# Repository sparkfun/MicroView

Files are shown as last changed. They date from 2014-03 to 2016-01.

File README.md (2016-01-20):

MicroView
=============

MicroView

[*SparkFun Microview (DEV-12923)*](https://www.sparkfun.com/products/12923)

The MicroView is a chip-sized Arduino with a built-in OLED. Compatible with the MicroView USB Programmer linked below. 

Repository Contents
-------------------
* **/Datasheets** - Datasheets for the OLED module
* **/Enclosure** - 3D model of the standard Microview Enclosure
* **/Hardware** - All Eagle design files (.brd, .sch)
* **/Libraries** - All Arduino libraries and board examples
* **/Production** - Test bed files and production panel files

Product Versions
----------------
* [DEV-12923](https://www.sparkfun.com/products/12923)- Version 1.0
* [DEV-12924](https://www.sparkfun.com/products/12924)- MicroView USB Programmer version 0.2

License Information
-------------------
The hardware is released under [Creative Commons ShareAlike 4.0 International](https://creativecommons.org/licenses/by-sa/4.0/).
The code is beerware; if you see me (or any other SparkFun employee) at the local, and you've found our code helpful, please buy us a round!

Distributed as-is; no warranty is given.

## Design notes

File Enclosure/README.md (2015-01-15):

MicroView-Enclosure
===================

MicroView Enclosure as 3D printable STL Files

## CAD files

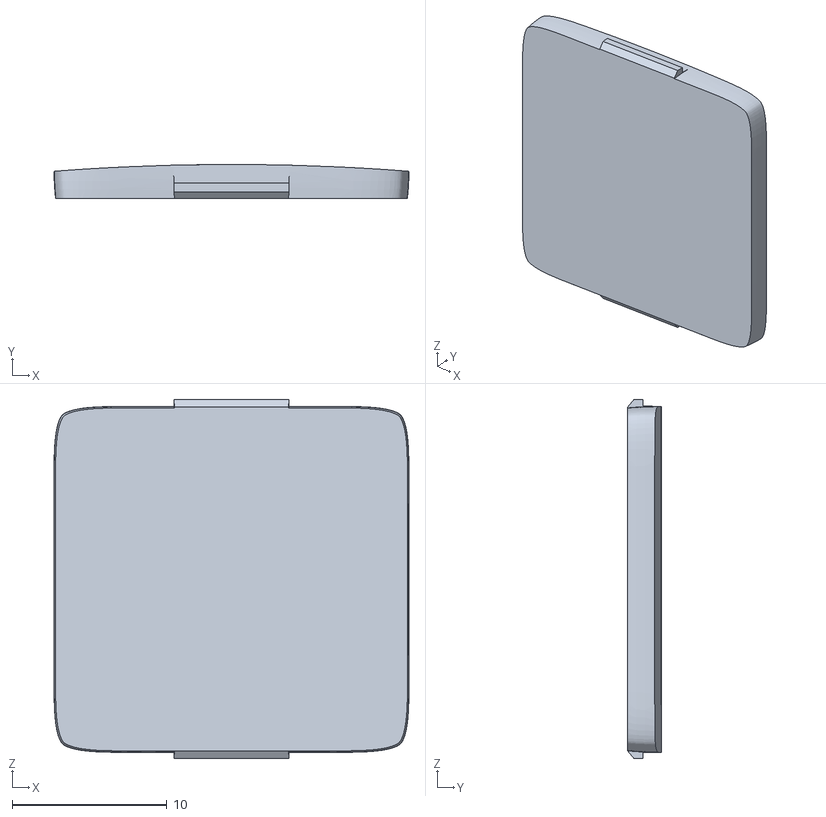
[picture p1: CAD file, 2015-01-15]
Enclosure/GKM-001_R05_ASSY_CHIP - GKM-002_R05_CHIP_UPPER_HOUSING-1.STL
22.9 x 2.20 x 23.2

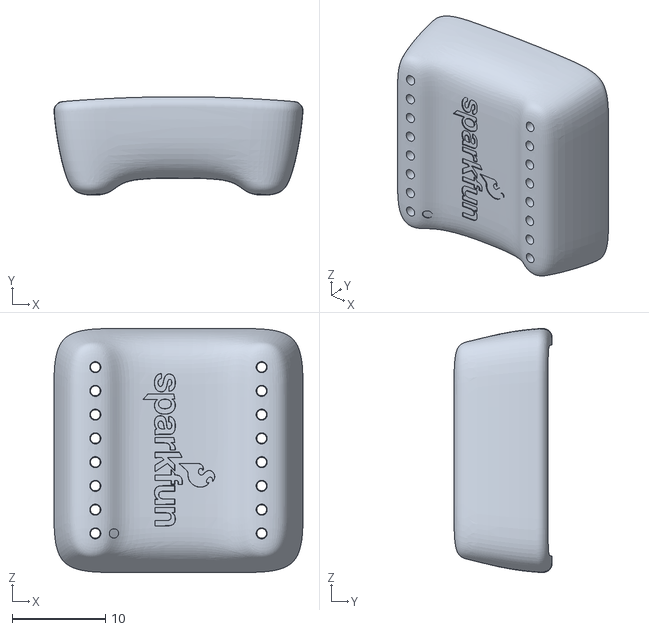
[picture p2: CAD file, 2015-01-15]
Enclosure/GKM-001_R05_ASSY_CHIP - GKM-003_R05_CHIP_LOWER_HOUSING-1.STL
26.7 x 10.5 x 26.1

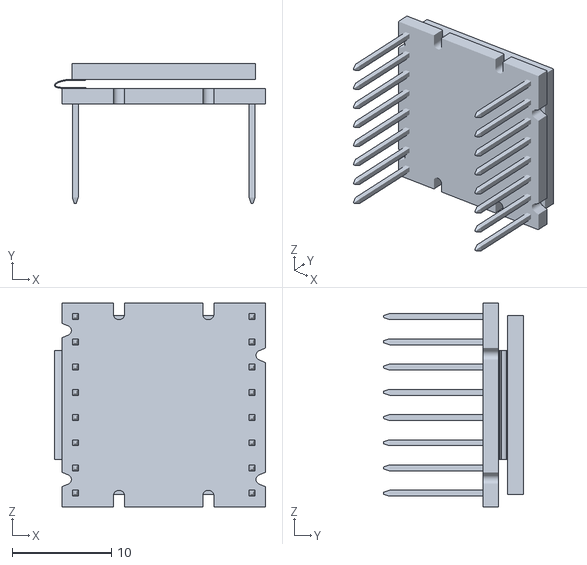
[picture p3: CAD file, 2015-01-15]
Enclosure/GKM-001_R05_ASSY_CHIP - GKM-004_R02_ASSY_MICROVIEW_PCB-3.STL
21.2 x 14.1 x 20.5

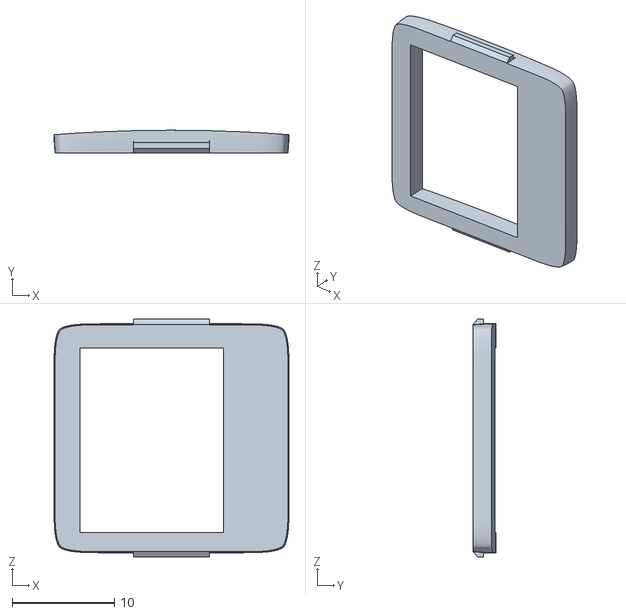
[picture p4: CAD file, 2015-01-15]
Enclosure/GKM-002_R05_CHIP_WINDOWED_UPPER_HOUSING.stl
22.9 x 2.20 x 23.2

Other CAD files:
Enclosure/GKM-003_R05_CHIP_LOWER_HOUSING.STL
Enclosure/GKM-002_R05_CHIP_UPPER_HOUSING.STL
Hardware/MicroView/Models/MicroView-PCB-Assembly_SCALED.skp

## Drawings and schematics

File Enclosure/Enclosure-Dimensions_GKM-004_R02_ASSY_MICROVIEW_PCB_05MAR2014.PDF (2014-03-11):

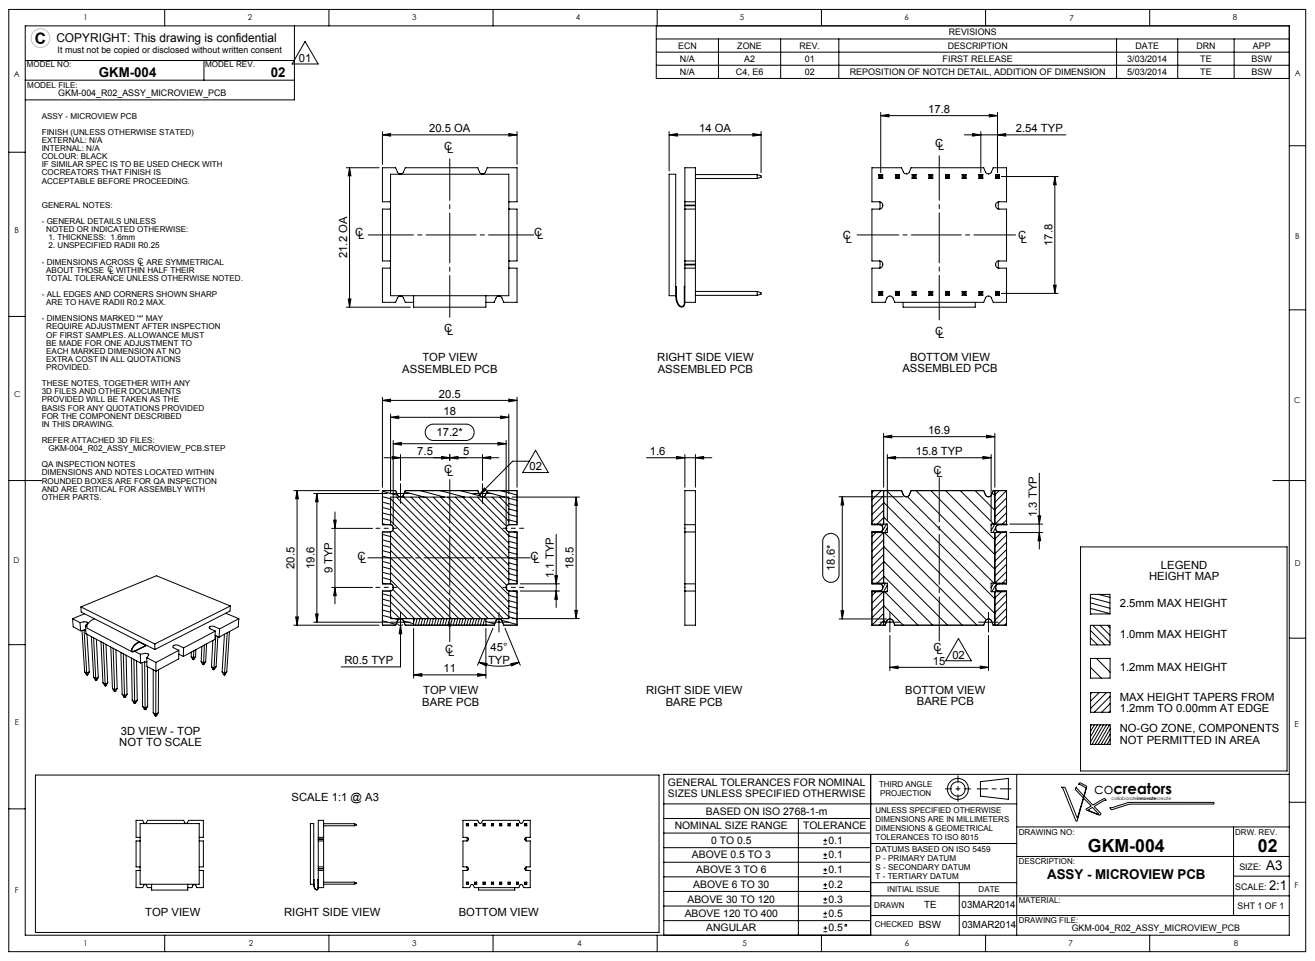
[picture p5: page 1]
1.1 TYP; R0.5 TYP; 9 TYP; TOP VIEW BARE PCB; 15.8 TYP; 1.3 TYP; BOTTOM VIEW BARE PCB; TOP VIEW ASSEMBLED PCB; 2.54 TYP; BOTTOM VIEW ASSEMBLED PCB; TOP VIEW; RIGHT SIDE VIEW; BOTTOM VIEW; 1.0mm MAX HEIGHT; 1.2mm MAX HEIGHT; HEIGHT MAP; SCALE 1:1 @ A3; 2.5mm MAX HEIGHT; SHT 1 OF 1; SCALE: 2:1; DRW. REV.; DRAWING FILE:; SIZE: A3; MODEL REV.; INITIAL ISSUE; DATE; CHECKED 0.5; SIZES UNLESS SPECIFIED OTHERWISE; collaborateinnovatecreate

COPYRIGHT: This drawing is confidential
It must not be copied or disclosed without written consent
MODEL NO:
MODEL FILE:
GKM-004_R02_ASSY_MICROVIEW_PCB

ECN | ZONE | REV. | DESCRIPTION | DATE | DRN | APP
N/A | A2 | 01 | FIRST RELEASE | 3/03/2014 | TE | BSW
N/A | C4, E6 | 02 | REPOSITION OF NOTCH DETAIL, ADDITION OF DIMENSION | 5/03/2014 | TE | BSW

ASSY - MICROVIEW PCB
FINISH (UNLESS OTHERWISE STATED)
EXTERNAL: N/A
INTERNAL: N/A
COLOUR: BLACK
IF SIMILAR SPEC IS TO BE USED CHECK WITH
COCREATORS THAT FINISH IS
ACCEPTABLE BEFORE PROCEEDING.

GENERAL NOTES:
- GENERAL DETAILS UNLESS
NOTED OR INDICATED OTHERWISE:

1. THICKNESS: 1.6mm
2. UNSPECIFIED RADII R0.25
- DIMENSIONS ACROSS CL ARE SYMMETRICAL
ABOUT THOSE CL WITHIN HALF THEIR
TOTAL TOLERANCE UNLESS OTHERWISE NOTED.
- ALL EDGES AND CORNERS SHOWN SHARP
ARE TO HAVE RADII R0.2 MAX.
- DIMENSIONS MARKED '*' MAY
REQUIRE ADJUSTMENT AFTER INSPECTION
OF FIRST SAMPLES. ALLOWANCE MUST
BE MADE FOR ONE ADJUSTMENT TO
EACH MARKED DIMENSION AT NO
EXTRA COST IN ALL QUOTATIONS
PROVIDED.
THESE NOTES, TOGETHER WITH ANY
3D FILES AND OTHER DOCUMENTS
PROVIDED WILL BE TAKEN AS THE
BASIS FOR ANY QUOTATIONS PROVIDED
FOR THE COMPONENT DESCRIBED
IN THIS DRAWING.
REFER ATTACHED 3D FILES:
GKM-004_R02_ASSY_MICROVIEW_PCB.STEP
QA INSPECTION NOTES
DIMENSIONS AND NOTES LOCATED WITHIN
ROUNDED BOXES ARE FOR QA INSPECTION
AND ARE CRITICAL FOR ASSEMBLY WITH
OTHER PARTS.

RIGHT SIDE VIEW
ASSEMBLED PCB

BARE PCB

MAX HEIGHT TAPERS FROM
1.2mm TO 0.00mm AT EDGE
NO-GO ZONE, COMPONENTS
NOT PERMITTED IN AREA

3D VIEW - TOP
NOT TO SCALE

GENERAL TOLERANCES FOR NOMINAL
BASED ON ISO 2768-1-m
NOMINAL SIZE RANGE TOLERANCE
ABOVE 0.5 TO 3
ABOVE 3 TO 6
ABOVE 6 TO 30
ABOVE 30 TO 120
ABOVE 120 TO 400
ANGULAR

THIRD ANGLE
PROJECTION
UNLESS SPECIFIED OTHERWISE
DIMENSIONS ARE IN MILLIMETERS
DIMENSIONS & GEOMETRICAL
TOLERANCES TO ISO 8015
DATUMS BASED ON ISO 5459
P - PRIMARY DATUM
S - SECONDARY DATUM
T - TERTIARY DATUM
03MAR2014

DRAWING NO:

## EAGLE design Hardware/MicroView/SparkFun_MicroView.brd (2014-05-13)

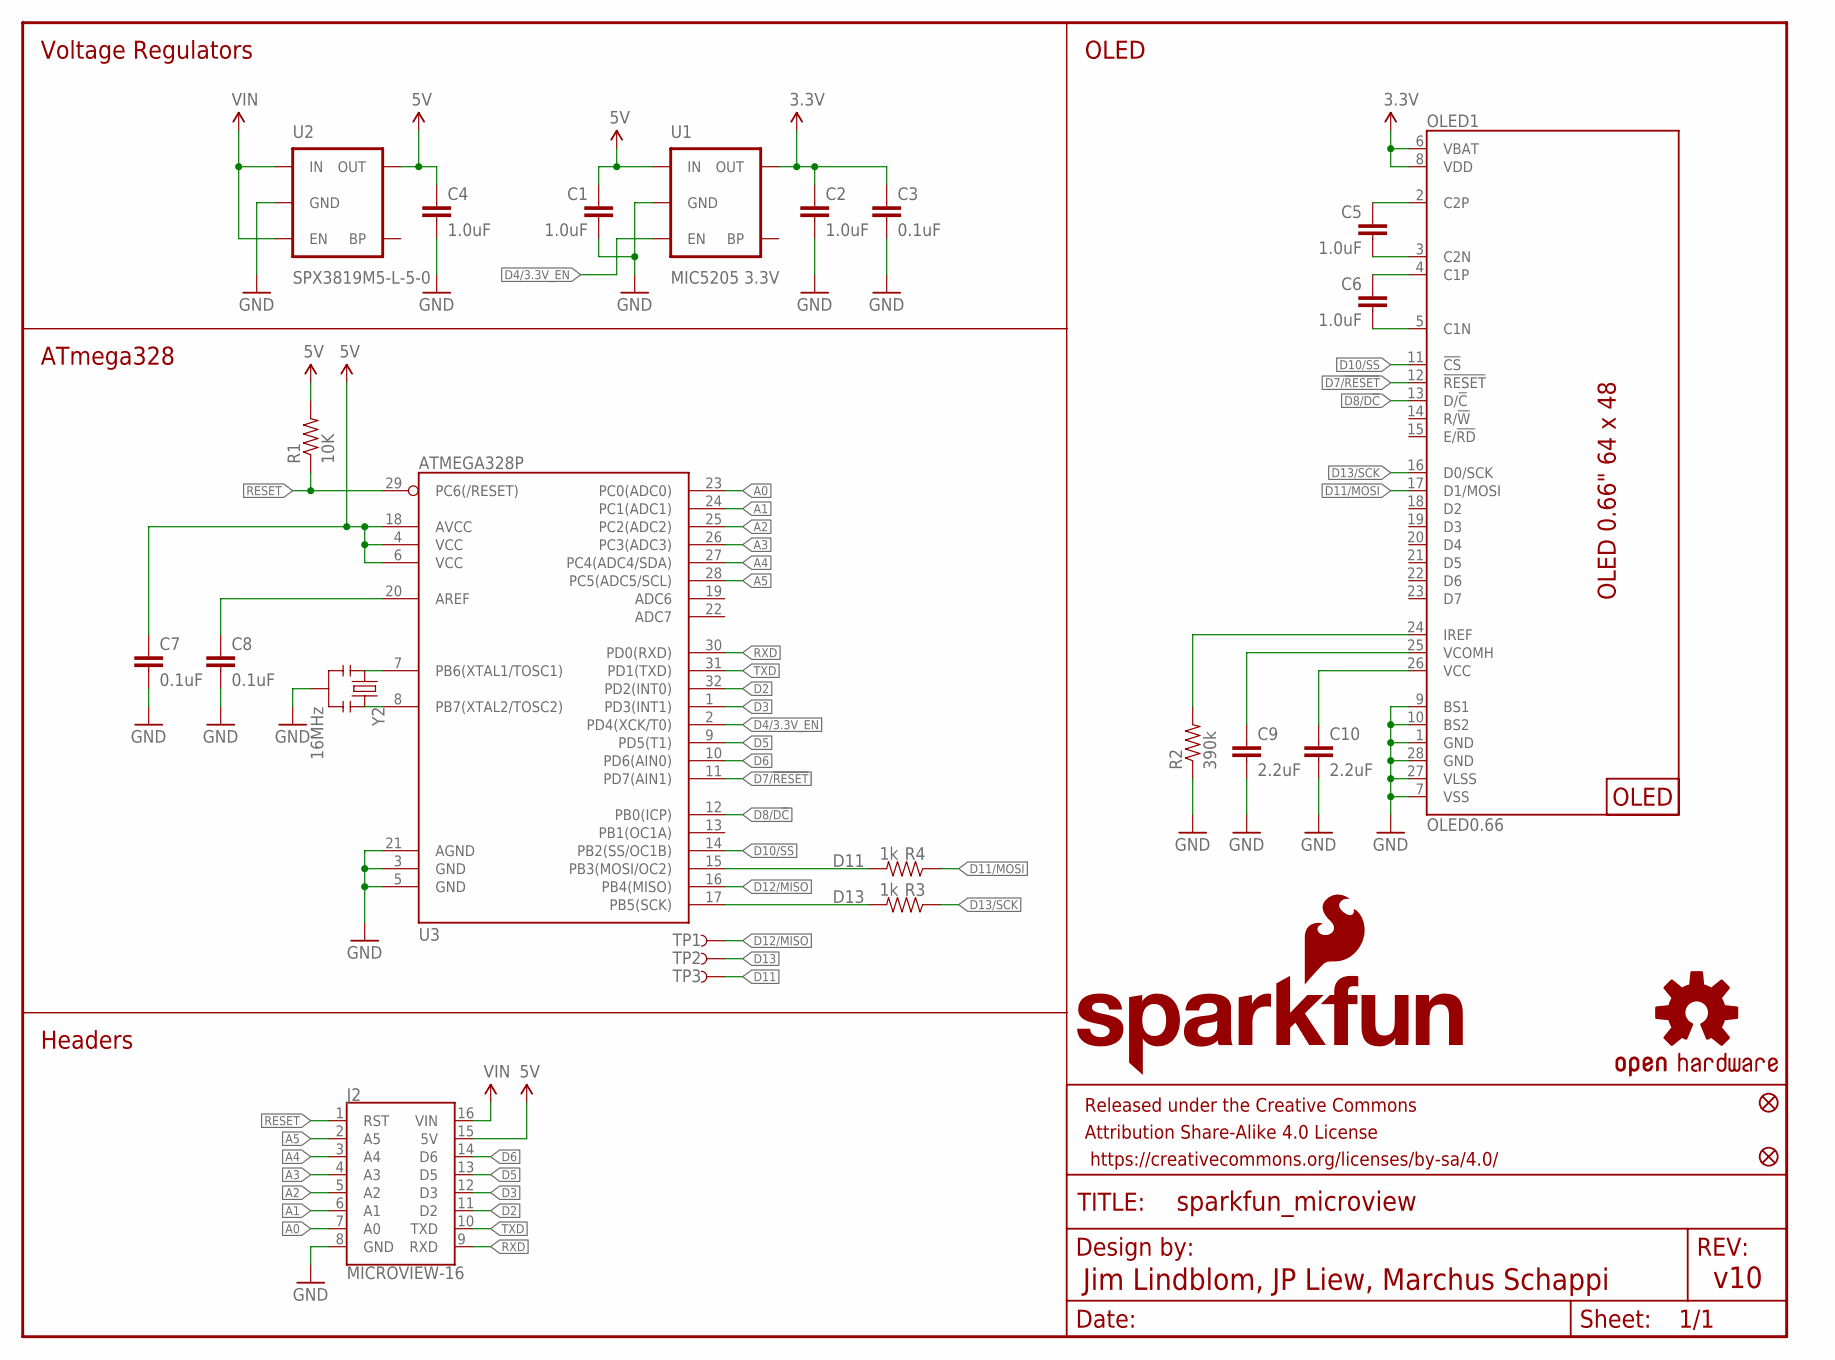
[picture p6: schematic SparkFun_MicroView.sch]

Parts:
C1, C2, C4, C5, C6: 1.0uF; 0603-CAP
C3, C7, C8: 0.1uF; 0603-CAP
C9, C10: 2.2uF; 0603-CAP
FID1, FID3: FIDUCIALUFIDUCIAL; MICRO-FIDUCIAL
FRAME1: FRAME-LETTER; CREATIVE_COMMONS
J1: OLED_SCREEN; OLED-SCREEN
J2: MICROVIEW-16; MV-DIP16
LOGO1: OSHW-LOGOS; OSHW-LOGO-S
LOGO4: SFE_LOGO_NAME_FLAME.1_INCH; SFE_LOGO_NAME_FLAME_.1
OLED1: OLED0.66; OLED-0.66-64X48
R1: 10K; 0603-RES
R2: 390k; 0603-RES
R3, R4: 1k; 0603-RES
TP1, TP2, TP3: TEST-POINT3X5; PAD.03X.05
U1: MIC5205 3.3V; SOT23-5
U2: SPX3819M5-L-5-0; SOT23-5
U3: ATMEGA328P; TQFP32-08
Y2: 16MHz; RESONATOR-SMD

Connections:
3.3V: C2.1, C3.1, OLED1.6 (VBAT), OLED1.8 (VDD), U1.5 (OUT)
5V: C1.1, C4.1, C7.1, J2.15 (5V), R1.2, U1.1 (IN), U2.5 (OUT), U3.4 (VCC), U3.6 (VCC), U3.18 (AVCC)
A0: J2.7 (A0), U3.23 (PC0(ADC0))
A1: J2.6 (A1), U3.24 (PC1(ADC1))
A2: J2.5 (A2), U3.25 (PC2(ADC2))
A3: J2.4 (A3), U3.26 (PC3(ADC3))
A4: J2.3 (A4), U3.27 (PC4(ADC4/SDA))
A5: J2.2 (A5), U3.28 (PC5(ADC5/SCL))
C1N: C6.2, OLED1.5 (C1N)
C1P: C6.1, OLED1.4 (C1P)
C2N: C5.2, OLED1.3 (C2N)
C2P: C5.1, OLED1.2 (C2P)
D2: J2.11 (D2), U3.32 (PD2(INT0))
D3: J2.12 (D3), U3.1 (PD3(INT1))
D4/3.3V_EN: U1.3 (EN), U3.2 (PD4(XCK/T0))
D5: J2.13 (D5), U3.9 (PD5(T1))
D6: J2.14 (D6), U3.10 (PD6(AIN0))
D7/!RESET!: OLED1.12 (!RESET!), U3.11 (PD7(AIN1))
D8/D!C!: OLED1.13 (D/!C!), U3.12 (PB0(ICP))
D10/SS: OLED1.11 (!CS!), U3.14 (PB2(SS/OC1B))
D11: R4.2, TP3.P$1, U3.15 (PB3(MOSI/OC2))
D11/MOSI: OLED1.17 (D1/MOSI), R4.1
D12/MISO: TP1.P$1, U3.16 (PB4(MISO))
D13: R3.2, TP2.P$1, U3.17 (PB5(SCK))
D13/SCK: OLED1.16 (D0/SCK), R3.1
GND: C1.2, C2.2, C3.2, C4.2, C7.2, C8.2, C9.2, C10.2, J2.8 (GND), OLED1.1 (GND), OLED1.7 (VSS), OLED1.9 (BS1), OLED1.10 (BS2), OLED1.27 (VLSS), OLED1.28 (GND), R2.1, U1.2 (GND), U2.2 (GND), U3.3 (GND), U3.5 (GND), U3.21 (AGND), Y2.2
unnamed: C10.1, OLED1.26 (VCC)
unnamed: C9.1, OLED1.25 (VCOMH)
unnamed: OLED1.24 (IREF), R2.2
unnamed: U3.7 (PB6(XTAL1/TOSC1)), Y2.1
unnamed: U3.8 (PB7(XTAL2/TOSC2)), Y2.3
unnamed: C8.1, U3.20 (AREF)
RESET: J2.1 (RST), R1.1, U3.29 (PC6(/RESET))
RXD: J2.9 (RXD), U3.30 (PD0(RXD))
TXD: J2.10 (TXD), U3.31 (PD1(TXD))
VIN: J2.16 (VIN), U2.1 (IN), U2.3 (EN)

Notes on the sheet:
v10
Jim Lindblom, JP Liew, Marchus Schappi
Voltage Regulators
ATmega328
OLED
Headers

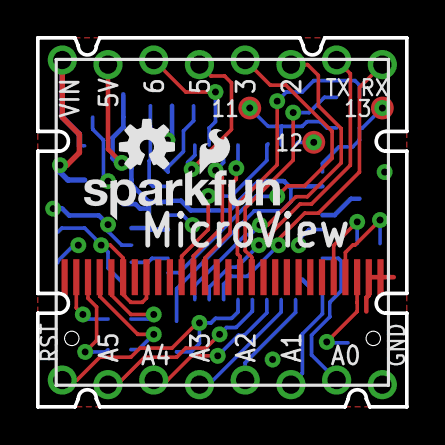
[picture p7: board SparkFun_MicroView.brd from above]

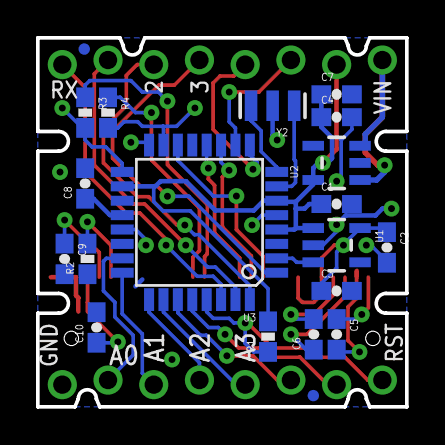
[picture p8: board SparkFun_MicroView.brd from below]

Board: 2 copper layers, 20.5 x 20.5 mm, 29 parts (20 on the bottom side), 36 nets.

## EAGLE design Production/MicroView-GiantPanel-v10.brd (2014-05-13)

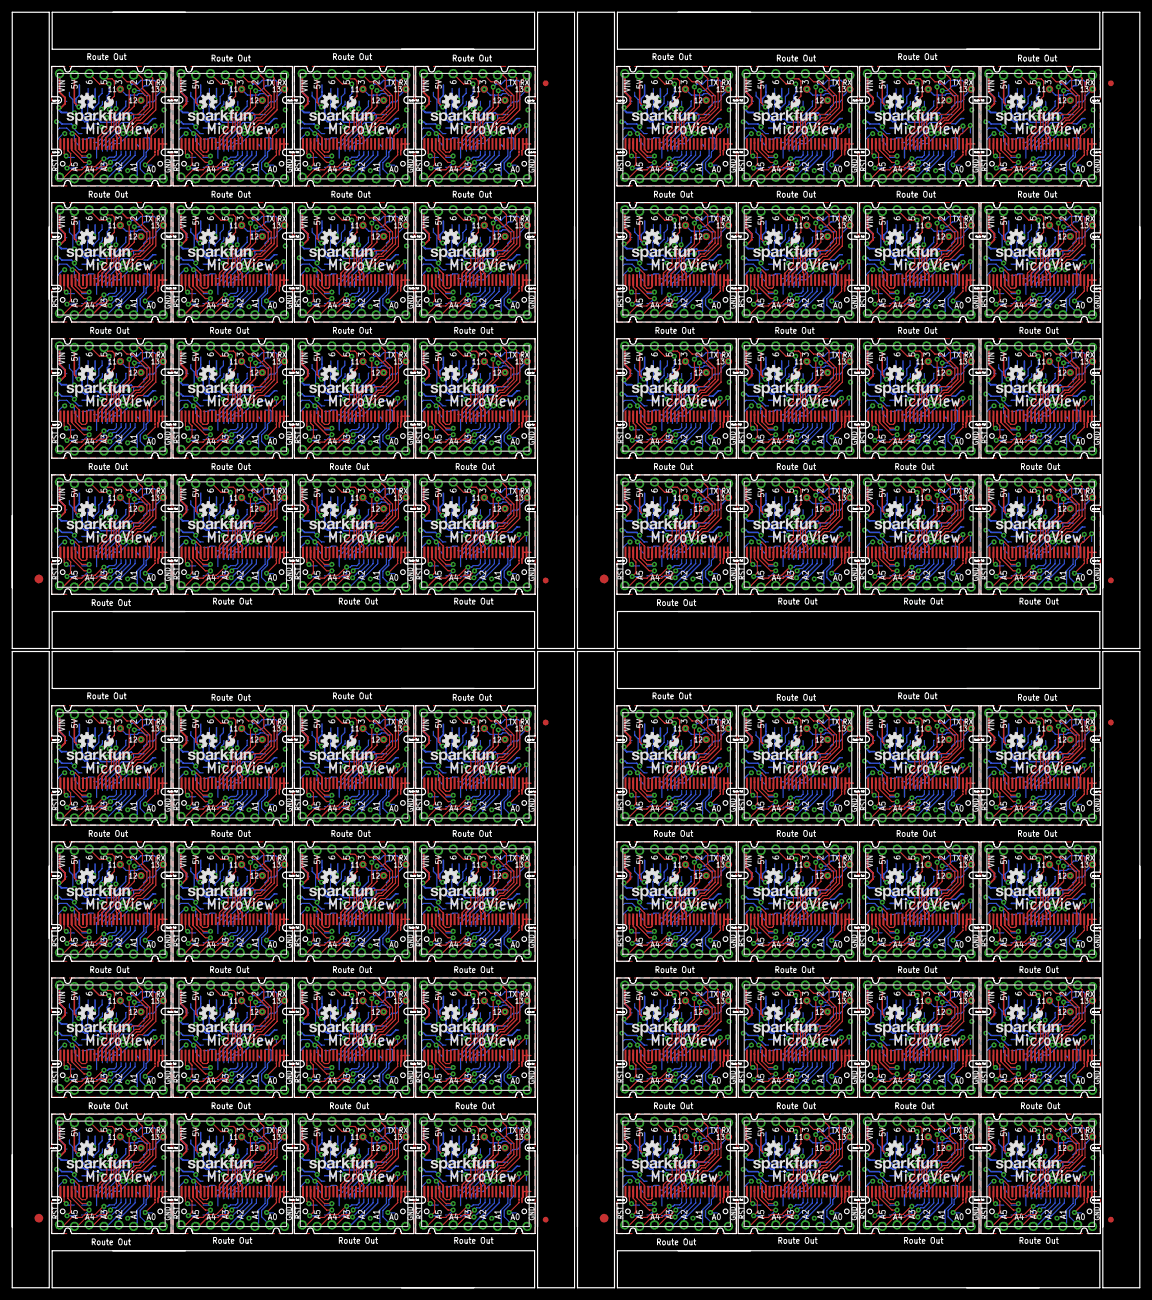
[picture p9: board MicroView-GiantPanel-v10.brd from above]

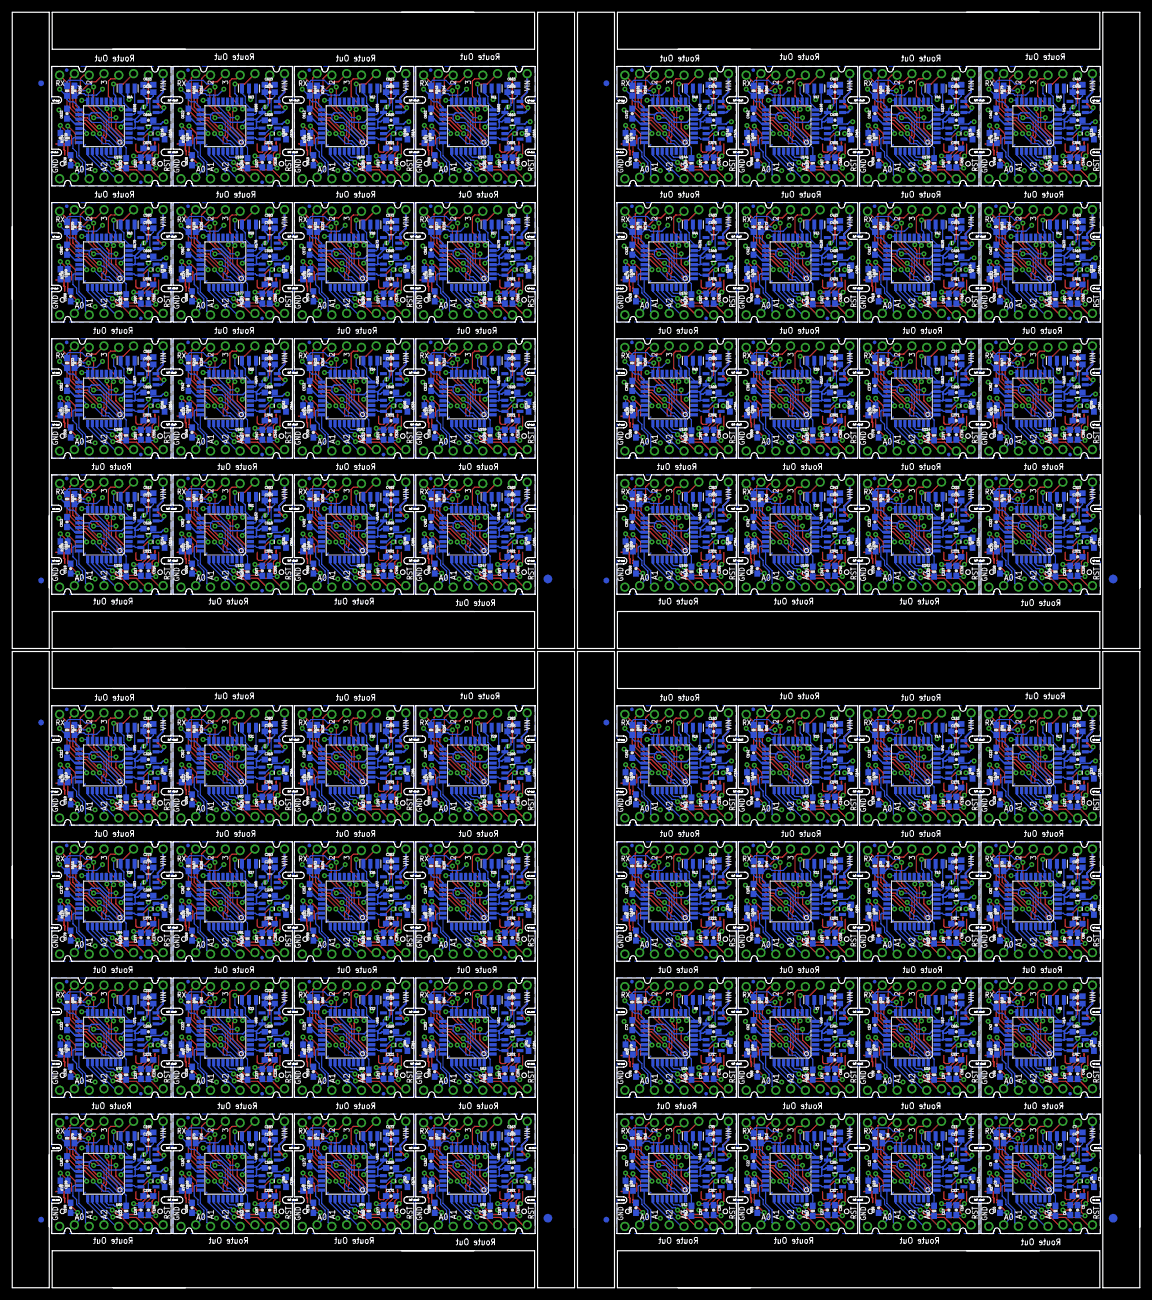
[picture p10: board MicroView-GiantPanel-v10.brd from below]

Board: 2 copper layers, 193.5 x 218.9 mm, 1816 parts (1292 on the bottom side), 2304 nets.

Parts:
C1, C2, C4, C5, C6, C14, C15, C16, C17, C20, C24, C25, C26, C27, C30, C34, C35, C36, C37, C40, C44, C45, C46, C47, C50, C54, C55, C56, C57, C60, C64, C65, C66, C67, C70, C74, C75, C76, C77, C80, C84, C85, C86, C87, C90, C94, C95, C96, C97, C100, C104, C105, C106, C107, C110, C114, C115, C116, C117, C120, C124, C125, C126, C127, C130, C134, C135, C136, C137, C140, C144, C145, C146, C147, C150, C154, C155, C156, C157, C160, C164, C165, C166, C167, C170, C174, C175, C176, C177, C180, C184, C185, C186, C187, C190, C194, C195, C196, C197, C200, C204, C205, C206, C207, C210, C214, C215, C216, C217, C220, C224, C225, C226, C227, C230, C234, C235, C236, C237, C240, C244, C245, C246, C247, C250, C254, C255, C256, C257, C260, C264, C265, C266, C267, C270, C274, C275, C276, C277, C280, C284, C285, C286, C287, C290, C294, C295, C296, C297, C300, C304, C305, C306, C307, C310, C314, C315, C316, C317, C320, C324, C325, C326, C327, C330, C334, C335, C336, C337, C340, C344, C345, C346, C347, C350, C354, C355, C356, C357, C360, C364, C365, C366, C367, C370, C374, C375, C376, C377, C380, C384, C385, C386, C387, C390, C394, C395, C396, C397, C400, C404, C405, C406, C407, C410, C414, C415, C416, C417, C420, C424, C425, C426, C427, C430, C434, C435, C436, C437, C440, C444, C445, C446, C447, C450, C454, C455, C456, C457, C460, C464, C465, C466, C467, C470, C474, C475, C476, C477, C480, C484, C485, C486, C487, C490, C494, C495, C496, C497, C500, C504, C505, C506, C507, C510, C514, C515, C516, C517, C520, C524, C525, C526, C527, C530, C534, C535, C536, C537, C540, C544, C545, C546, C547, C550, C554, C555, C556, C557, C560, C564, C565, C566, C567, C570, C574, C575, C576, C577, C580, C584, C585, C586, C587, C590, C594, C595, C596, C597, C600, C604, C605, C606, C607, C610, C614, C615, C616, C617, C620, C624, C625, C626, C627, C630, C634, C635, C636, C637, C640: 1.0uF; 0603-CAP
C3, C7, C8, C11, C12, C13, C21, C22, C23, C31, C32, C33, C41, C42, C43, C51, C52, C53, C61, C62, C63, C71, C72, C73, C81, C82, C83, C91, C92, C93, C101, C102, C103, C111, C112, C113, C121, C122, C123, C131, C132, C133, C141, C142, C143, C151, C152, C153, C161, C162, C163, C171, C172, C173, C181, C182, C183, C191, C192, C193, C201, C202, C203, C211, C212, C213, C221, C222, C223, C231, C232, C233, C241, C242, C243, C251, C252, C253, C261, C262, C263, C271, C272, C273, C281, C282, C283, C291, C292, C293, C301, C302, C303, C311, C312, C313, C321, C322, C323, C331, C332, C333, C341, C342, C343, C351, C352, C353, C361, C362, C363, C371, C372, C373, C381, C382, C383, C391, C392, C393, C401, C402, C403, C411, C412, C413, C421, C422, C423, C431, C432, C433, C441, C442, C443, C451, C452, C453, C461, C462, C463, C471, C472, C473, C481, C482, C483, C491, C492, C493, C501, C502, C503, C511, C512, C513, C521, C522, C523, C531, C532, C533, C541, C542, C543, C551, C552, C553, C561, C562, C563, C571, C572, C573, C581, C582, C583, C591, C592, C593, C601, C602, C603, C611, C612, C613, C621, C622, C623, C631, C632, C633: 0.1uF; 0603-CAP
C9, C10, C18, C19, C28, C29, C38, C39, C48, C49, C58, C59, C68, C69, C78, C79, C88, C89, C98, C99, C108, C109, C118, C119, C128, C129, C138, C139, C148, C149, C158, C159, C168, C169, C178, C179, C188, C189, C198, C199, C208, C209, C218, C219, C228, C229, C238, C239, C248, C249, C258, C259, C268, C269, C278, C279, C288, C289, C298, C299, C308, C309, C318, C319, C328, C329, C338, C339, C348, C349, C358, C359, C368, C369, C378, C379, C388, C389, C398, C399, C408, C409, C418, C419, C428, C429, C438, C439, C448, C449, C458, C459, C468, C469, C478, C479, C488, C489, C498, C499, C508, C509, C518, C519, C528, C529, C538, C539, C548, C549, C558, C559, C568, C569, C578, C579, C588, C589, C598, C599, C608, C609, C618, C619, C628, C629, C638, C639: 2.2uF; 0603-CAP
E$1, E$2, E$9, E$10, E$15, E$16, E$21, E$22: FIDUCIAL-1.5X3
E$3, E$4, E$5, E$6, E$7, E$8, E$11, E$12, E$13, E$14, E$17, E$18, E$19, E$20, E$23, E$24: FIDUCIAL-1X2
FID1, FID2, FID3, FID4, FID5, FID6, FID7, FID8, FID9, FID10, FID11, FID12, FID13, FID14, FID15, FID16, FID17, FID18, FID19, FID20, FID21, FID22, FID23, FID24, FID25, FID26, FID27, FID28, FID29, FID30, FID31, FID32, FID33, FID34, FID35, FID36, FID37, FID38, FID39, FID40, FID41, FID42, FID43, FID44, FID45, FID46, FID47, FID48, FID49, FID50, FID51, FID52, FID53, FID54, FID55, FID56, FID57, FID58, FID59, FID60, FID61, FID62, FID63, FID64, FID65, FID66, FID67, FID68, FID69, FID70, FID71, FID72, FID73, FID74, FID75, FID76, FID77, FID78, FID79, FID80, FID81, FID82, FID83, FID84, FID85, FID86, FID87, FID88, FID89, FID90, FID91, FID92, FID93, FID94, FID95, FID96, FID97, FID98, FID99, FID100, FID101, FID102, FID103, FID104, FID105, FID106, FID107, FID108, FID109, FID110, FID111, FID112, FID113, FID114, FID115, FID116, FID117, FID118, FID119, FID120, FID121, FID122, FID123, FID124, FID125, FID126, FID127, FID128: FIDUCIALUFIDUCIAL; MICRO-FIDUCIAL
J1, J4, J6, J8, J10, J12, J14, J16, J18, J20, J22, J24, J26, J28, J30, J32, J34, J36, J38, J40, J42, J44, J46, J48, J50, J52, J54, J56, J58, J60, J62, J64, J66, J68, J70, J72, J74, J76, J78, J80, J82, J84, J86, J88, J90, J92, J94, J96, J98, J100, J102, J104, J106, J108, J110, J112, J114, J116, J118, J120, J122, J124, J126, J128: OLED_SCREEN; OLED-SCREEN
J2, J3, J5, J7, J9, J11, J13, J15, J17, J19, J21, J23, J25, J27, J29, J31, J33, J35, J37, J39, J41, J43, J45, J47, J49, J51, J53, J55, J57, J59, J61, J63, J65, J67, J69, J71, J73, J75, J77, J79, J81, J83, J85, J87, J89, J91, J93, J95, J97, J99, J101, J103, J105, J107, J109, J111, J113, J115, J117, J119, J121, J123, J125, J127: MICROVIEW-16; MV-DIP16
LOGO1, LOGO2, LOGO5, LOGO7, LOGO9, LOGO11, LOGO13, LOGO15, LOGO17, LOGO19, LOGO21, LOGO23, LOGO25, LOGO27, LOGO29, LOGO31, LOGO33, LOGO35, LOGO37, LOGO39, LOGO41, LOGO43, LOGO45, LOGO47, LOGO49, LOGO51, LOGO53, LOGO55, LOGO57, LOGO59, LOGO61, LOGO63, LOGO65, LOGO67, LOGO69, LOGO71, LOGO73, LOGO75, LOGO77, LOGO79, LOGO81, LOGO83, LOGO85, LOGO87, LOGO89, LOGO91, LOGO93, LOGO95, LOGO97, LOGO99, LOGO101, LOGO103, LOGO105, LOGO107, LOGO109, LOGO111, LOGO113, LOGO115, LOGO117, LOGO119, LOGO121, LOGO123, LOGO125, LOGO127: OSHW-LOGOS; OSHW-LOGO-S
LOGO3, LOGO4, LOGO6, LOGO8, LOGO10, LOGO12, LOGO14, LOGO16, LOGO18, LOGO20, LOGO22, LOGO24, LOGO26, LOGO28, LOGO30, LOGO32, LOGO34, LOGO36, LOGO38, LOGO40, LOGO42, LOGO44, LOGO46, LOGO48, LOGO50, LOGO52, LOGO54, LOGO56, LOGO58, LOGO60, LOGO62, LOGO64, LOGO66, LOGO68, LOGO70, LOGO72, LOGO74, LOGO76, LOGO78, LOGO80, LOGO82, LOGO84, LOGO86, LOGO88, LOGO90, LOGO92, LOGO94, LOGO96, LOGO98, LOGO100, LOGO102, LOGO104, LOGO106, LOGO108, LOGO110, LOGO112, LOGO114, LOGO116, LOGO118, LOGO120, LOGO122, LOGO124, LOGO126, LOGO128: SFE_LOGO_NAME_FLAME.1_INCH; SFE_LOGO_NAME_FLAME_.1
OLED1, OLED2, OLED3, OLED4, OLED5, OLED6, OLED7, OLED8, OLED9, OLED10, OLED11, OLED12, OLED13, OLED14, OLED15, OLED16, OLED17, OLED18, OLED19, OLED20, OLED21, OLED22, OLED23, OLED24, OLED25, OLED26, OLED27, OLED28, OLED29, OLED30, OLED31, OLED32, OLED33, OLED34, OLED35, OLED36, OLED37, OLED38, OLED39, OLED40, OLED41, OLED42, OLED43, OLED44, OLED45, OLED46, OLED47, OLED48, OLED49, OLED50, OLED51, OLED52, OLED53, OLED54, OLED55, OLED56, OLED57, OLED58, OLED59, OLED60, OLED61, OLED62, OLED63, OLED64: OLED0.66; OLED-0.66-64X48
R1, R5, R9, R13, R17, R21, R25, R29, R33, R37, R41, R45, R49, R53, R57, R61, R65, R69, R73, R77, R81, R85, R89, R93, R97, R101, R105, R109, R113, R117, R121, R125, R129, R133, R137, R141, R145, R149, R153, R157, R161, R165, R169, R173, R177, R181, R185, R189, R193, R197, R201, R205, R209, R213, R217, R221, R225, R229, R233, R237, R241, R245, R249, R253: 10K; 0603-RES
R2, R6, R10, R14, R18, R22, R26, R30, R34, R38, R42, R46, R50, R54, R58, R62, R66, R70, R74, R78, R82, R86, R90, R94, R98, R102, R106, R110, R114, R118, R122, R126, R130, R134, R138, R142, R146, R150, R154, R158, R162, R166, R170, R174, R178, R182, R186, R190, R194, R198, R202, R206, R210, R214, R218, R222, R226, R230, R234, R238, R242, R246, R250, R254: 390k; 0603-RES
R3, R4, R7, R8, R11, R12, R15, R16, R19, R20, R23, R24, R27, R28, R31, R32, R35, R36, R39, R40, R43, R44, R47, R48, R51, R52, R55, R56, R59, R60, R63, R64, R67, R68, R71, R72, R75, R76, R79, R80, R83, R84, R87, R88, R91, R92, R95, R96, R99, R100, R103, R104, R107, R108, R111, R112, R115, R116, R119, R120, R123, R124, R127, R128, R131, R132, R135, R136, R139, R140, R143, R144, R147, R148, R151, R152, R155, R156, R159, R160, R163, R164, R167, R168, R171, R172, R175, R176, R179, R180, R183, R184, R187, R188, R191, R192, R195, R196, R199, R200, R203, R204, R207, R208, R211, R212, R215, R216, R219, R220, R223, R224, R227, R228, R231, R232, R235, R236, R239, R240, R243, R244, R247, R248, R251, R252, R255, R256: 1k; 0603-RES
TP1, TP2, TP3, TP4, TP5, TP6, TP7, TP8, TP9, TP10, TP11, TP12, TP13, TP14, TP15, TP16, TP17, TP18, TP19, TP20, TP21, TP22, TP23, TP24, TP25, TP26, TP27, TP28, TP29, TP30, TP31, TP32, TP33, TP34, TP35, TP36, TP37, TP38, TP39, TP40, TP41, TP42, TP43, TP44, TP45, TP46, TP47, TP48, TP49, TP50, TP51, TP52, TP53, TP54, TP55, TP56, TP57, TP58, TP59, TP60, TP61, TP62, TP63, TP64, TP65, TP66, TP67, TP68, TP69, TP70, TP71, TP72, TP73, TP74, TP75, TP76, TP77, TP78, TP79, TP80, TP81, TP82, TP83, TP84, TP85, TP86, TP87, TP88, TP89, TP90, TP91, TP92, TP93, TP94, TP95, TP96, TP97, TP98, TP99, TP100, TP101, TP102, TP103, TP104, TP105, TP106, TP107, TP108, TP109, TP110, TP111, TP112, TP113, TP114, TP115, TP116, TP117, TP118, TP119, TP120, TP121, TP122, TP123, TP124, TP125, TP126, TP127, TP128, TP129, TP130, TP131, TP132, TP133, TP134, TP135, TP136, TP137, TP138, TP139, TP140, TP141, TP142, TP143, TP144, TP145, TP146, TP147, TP148, TP149, TP150, TP151, TP152, TP153, TP154, TP155, TP156, TP157, TP158, TP159, TP160, TP161, TP162, TP163, TP164, TP165, TP166, TP167, TP168, TP169, TP170, TP171, TP172, TP173, TP174, TP175, TP176, TP177, TP178, TP179, TP180, TP181, TP182, TP183, TP184, TP185, TP186, TP187, TP188, TP189, TP190, TP191, TP192: PAD.03X.05
U1, U4, U7, U10, U13, U16, U19, U22, U25, U28, U31, U34, U37, U40, U43, U46, U49, U52, U55, U58, U61, U64, U67, U70, U73, U76, U79, U82, U85, U88, U91, U94, U97, U100, U103, U106, U109, U112, U115, U118, U121, U124, U127, U130, U133, U136, U139, U142, U145, U148, U151, U154, U157, U160, U163, U166, U169, U172, U175, U178, U181, U184, U187, U190: MIC5205 3.3V; SOT23-5
U2, U5, U8, U11, U14, U17, U20, U23, U26, U29, U32, U35, U38, U41, U44, U47, U50, U53, U56, U59, U62, U65, U68, U71, U74, U77, U80, U83, U86, U89, U92, U95, U98, U101, U104, U107, U110, U113, U116, U119, U122, U125, U128, U131, U134, U137, U140, U143, U146, U149, U152, U155, U158, U161, U164, U167, U170, U173, U176, U179, U182, U185, U188, U191: SPX3819M5-L-5-0; SOT23-5
U3, U6, U9, U12, U15, U18, U21, U24, U27, U30, U33, U36, U39, U42, U45, U48, U51, U54, U57, U60, U63, U66, U69, U72, U75, U78, U81, U84, U87, U90, U93, U96, U99, U102, U105, U108, U111, U114, U117, U120, U123, U126, U129, U132, U135, U138, U141, U144, U147, U150, U153, U156, U159, U162, U165, U168, U171, U174, U177, U180, U183, U186, U189, U192: ATMEGA328P; TQFP32-08
Y1, Y2, Y3, Y4, Y5, Y6, Y7, Y8, Y9, Y10, Y11, Y12, Y13, Y14, Y15, Y16, Y17, Y18, Y19, Y20, Y21, Y22, Y23, Y24, Y25, Y26, Y27, Y28, Y29, Y30, Y31, Y32, Y33, Y34, Y35, Y36, Y37, Y38, Y39, Y40, Y41, Y42, Y43, Y44, Y45, Y46, Y47, Y48, Y49, Y50, Y51, Y52, Y53, Y54, Y55, Y56, Y57, Y58, Y59, Y60, Y61, Y62, Y63, Y64: 16MHz; RESONATOR-SMD

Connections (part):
3.3V: C2.1, C3.1, OLED1.6, OLED1.8, U1.5
3.3V1: C11.1, C14.1, OLED2.6, OLED2.8, U4.5
3.3V2: C21.1, C24.1, OLED3.6, OLED3.8, U7.5
3.3V3: C31.1, C34.1, OLED4.6, OLED4.8, U10.5
3.3V4: C41.1, C44.1, OLED5.6, OLED5.8, U13.5
3.3V5: C51.1, C54.1, OLED6.6, OLED6.8, U16.5
3.3V6: C61.1, C64.1, OLED7.6, OLED7.8, U19.5
3.3V7: C71.1, C74.1, OLED8.6, OLED8.8, U22.5
3.3V8: C81.1, C84.1, OLED9.6, OLED9.8, U25.5
3.3V9: C91.1, C94.1, OLED10.6, OLED10.8, U28.5
3.3V10: C101.1, C104.1, OLED11.6, OLED11.8, U31.5
3.3V11: C111.1, C114.1, OLED12.6, OLED12.8, U34.5
3.3V12: C121.1, C124.1, OLED13.6, OLED13.8, U37.5
3.3V13: C131.1, C134.1, OLED14.6, OLED14.8, U40.5
3.3V14: C141.1, C144.1, OLED15.6, OLED15.8, U43.5
3.3V15: C151.1, C154.1, OLED16.6, OLED16.8, U46.5
3.3V16: C161.1, C164.1, OLED17.6, OLED17.8, U49.5
3.3V17: C171.1, C174.1, OLED18.6, OLED18.8, U52.5
3.3V18: C181.1, C184.1, OLED19.6, OLED19.8, U55.5
3.3V19: C191.1, C194.1, OLED20.6, OLED20.8, U58.5
3.3V20: C201.1, C204.1, OLED21.6, OLED21.8, U61.5
3.3V21: C211.1, C214.1, OLED22.6, OLED22.8, U64.5
3.3V22: C221.1, C224.1, OLED23.6, OLED23.8, U67.5
3.3V23: C231.1, C234.1, OLED24.6, OLED24.8, U70.5
3.3V24: C241.1, C244.1, OLED25.6, OLED25.8, U73.5
3.3V25: C251.1, C254.1, OLED26.6, OLED26.8, U76.5
3.3V26: C261.1, C264.1, OLED27.6, OLED27.8, U79.5
3.3V27: C271.1, C274.1, OLED28.6, OLED28.8, U82.5
3.3V28: C281.1, C284.1, OLED29.6, OLED29.8, U85.5
3.3V29: C291.1, C294.1, OLED30.6, OLED30.8, U88.5
3.3V30: C301.1, C304.1, OLED31.6, OLED31.8, U91.5
3.3V31: C311.1, C314.1, OLED32.6, OLED32.8, U94.5
3.3V32: C321.1, C324.1, OLED33.6, OLED33.8, U97.5
3.3V33: C331.1, C334.1, OLED34.6, OLED34.8, U100.5
3.3V34: C341.1, C344.1, OLED35.6, OLED35.8, U103.5
3.3V35: C351.1, C354.1, OLED36.6, OLED36.8, U106.5
3.3V36: C361.1, C364.1, OLED37.6, OLED37.8, U109.5
3.3V37: C371.1, C374.1, OLED38.6, OLED38.8, U112.5
3.3V38: C381.1, C384.1, OLED39.6, OLED39.8, U115.5
3.3V39: C391.1, C394.1, OLED40.6, OLED40.8, U118.5
3.3V40: C401.1, C404.1, OLED41.6, OLED41.8, U121.5
3.3V41: C411.1, C414.1, OLED42.6, OLED42.8, U124.5
3.3V42: C421.1, C424.1, OLED43.6, OLED43.8, U127.5
3.3V43: C431.1, C434.1, OLED44.6, OLED44.8, U130.5
3.3V44: C441.1, C444.1, OLED45.6, OLED45.8, U133.5
3.3V45: C451.1, C454.1, OLED46.6, OLED46.8, U136.5
3.3V46: C461.1, C464.1, OLED47.6, OLED47.8, U139.5
3.3V47: C471.1, C474.1, OLED48.6, OLED48.8, U142.5
3.3V48: C481.1, C484.1, OLED49.6, OLED49.8, U145.5
3.3V49: C491.1, C494.1, OLED50.6, OLED50.8, U148.5
3.3V50: C501.1, C504.1, OLED51.6, OLED51.8, U151.5
3.3V51: C511.1, C514.1, OLED52.6, OLED52.8, U154.5
3.3V52: C521.1, C524.1, OLED53.6, OLED53.8, U157.5
3.3V53: C531.1, C534.1, OLED54.6, OLED54.8, U160.5
3.3V54: C541.1, C544.1, OLED55.6, OLED55.8, U163.5
3.3V55: C551.1, C554.1, OLED56.6, OLED56.8, U166.5
3.3V56: C561.1, C564.1, OLED57.6, OLED57.8, U169.5
3.3V57: C571.1, C574.1, OLED58.6, OLED58.8, U172.5
3.3V58: C581.1, C584.1, OLED59.6, OLED59.8, U175.5
3.3V59: C591.1, C594.1, OLED60.6, OLED60.8, U178.5
3.3V60: C601.1, C604.1, OLED61.6, OLED61.8, U181.5
3.3V61: C611.1, C614.1, OLED62.6, OLED62.8, U184.5
3.3V62: C621.1, C624.1, OLED63.6, OLED63.8, U187.5
3.3V63: C631.1, C634.1, OLED64.6, OLED64.8, U190.5
5V: C1.1, C4.1, C7.1, J2.15, R1.2, U1.1, U2.5, U3.4, U3.6, U3.18
5V1: C13.1, C15.1, C20.1, J3.15, R5.2, U4.1, U5.5, U6.4, U6.6, U6.18
5V2: C23.1, C25.1, C30.1, J5.15, R9.2, U7.1, U8.5, U9.4, U9.6, U9.18
5V3: C33.1, C35.1, C40.1, J7.15, R13.2, U10.1, U11.5, U12.4, U12.6, U12.18
5V4: C43.1, C45.1, C50.1, J9.15, R17.2, U13.1, U14.5, U15.4, U15.6, U15.18
5V5: C53.1, C55.1, C60.1, J11.15, R21.2, U16.1, U17.5, U18.4, U18.6, U18.18
5V6: C63.1, C65.1, C70.1, J13.15, R25.2, U19.1, U20.5, U21.4, U21.6, U21.18
5V7: C73.1, C75.1, C80.1, J15.15, R29.2, U22.1, U23.5, U24.4, U24.6, U24.18
5V8: C83.1, C85.1, C90.1, J17.15, R33.2, U25.1, U26.5, U27.4, U27.6, U27.18
5V9: C93.1, C95.1, C100.1, J19.15, R37.2, U28.1, U29.5, U30.4, U30.6, U30.18
5V10: C103.1, C105.1, C110.1, J21.15, R41.2, U31.1, U32.5, U33.4, U33.6, U33.18
5V11: C113.1, C115.1, C120.1, J23.15, R45.2, U34.1, U35.5, U36.4, U36.6, U36.18
5V12: C123.1, C125.1, C130.1, J25.15, R49.2, U37.1, U38.5, U39.4, U39.6, U39.18
5V13: C133.1, C135.1, C140.1, J27.15, R53.2, U40.1, U41.5, U42.4, U42.6, U42.18
5V14: C143.1, C145.1, C150.1, J29.15, R57.2, U43.1, U44.5, U45.4, U45.6, U45.18
5V15: C153.1, C155.1, C160.1, J31.15, R61.2, U46.1, U47.5, U48.4, U48.6, U48.18
5V16: C163.1, C165.1, C170.1, J33.15, R65.2, U49.1, U50.5, U51.4, U51.6, U51.18
5V17: C173.1, C175.1, C180.1, J35.15, R69.2, U52.1, U53.5, U54.4, U54.6, U54.18
5V18: C183.1, C185.1, C190.1, J37.15, R73.2, U55.1, U56.5, U57.4, U57.6, U57.18
5V19: C193.1, C195.1, C200.1, J39.15, R77.2, U58.1, U59.5, U60.4, U60.6, U60.18
5V20: C203.1, C205.1, C210.1, J41.15, R81.2, U61.1, U62.5, U63.4, U63.6, U63.18
5V21: C213.1, C215.1, C220.1, J43.15, R85.2, U64.1, U65.5, U66.4, U66.6, U66.18
5V22: C223.1, C225.1, C230.1, J45.15, R89.2, U67.1, U68.5, U69.4, U69.6, U69.18
5V23: C233.1, C235.1, C240.1, J47.15, R93.2, U70.1, U71.5, U72.4, U72.6, U72.18
5V24: C243.1, C245.1, C250.1, J49.15, R97.2, U73.1, U74.5, U75.4, U75.6, U75.18
5V25: C253.1, C255.1, C260.1, J51.15, R101.2, U76.1, U77.5, U78.4, U78.6, U78.18
5V26: C263.1, C265.1, C270.1, J53.15, R105.2, U79.1, U80.5, U81.4, U81.6, U81.18
5V27: C273.1, C275.1, C280.1, J55.15, R109.2, U82.1, U83.5, U84.4, U84.6, U84.18
5V28: C283.1, C285.1, C290.1, J57.15, R113.2, U85.1, U86.5, U87.4, U87.6, U87.18
5V29: C293.1, C295.1, C300.1, J59.15, R117.2, U88.1, U89.5, U90.4, U90.6, U90.18
5V30: C303.1, C305.1, C310.1, J61.15, R121.2, U91.1, U92.5, U93.4, U93.6, U93.18
5V31: C313.1, C315.1, C320.1, J63.15, R125.2, U94.1, U95.5, U96.4, U96.6, U96.18
5V32: C323.1, C325.1, C330.1, J65.15, R129.2, U97.1, U98.5, U99.4, U99.6, U99.18
5V33: C333.1, C335.1, C340.1, J67.15, R133.2, U100.1, U101.5, U102.4, U102.6, U102.18
5V34: C343.1, C345.1, C350.1, J69.15, R137.2, U103.1, U104.5, U105.4, U105.6, U105.18
5V35: C353.1, C355.1, C360.1, J71.15, R141.2, U106.1, U107.5, U108.4, U108.6, U108.18
5V36: C363.1, C365.1, C370.1, J73.15, R145.2, U109.1, U110.5, U111.4, U111.6, U111.18
5V37: C373.1, C375.1, C380.1, J75.15, R149.2, U112.1, U113.5, U114.4, U114.6, U114.18
5V38: C383.1, C385.1, C390.1, J77.15, R153.2, U115.1, U116.5, U117.4, U117.6, U117.18
5V39: C393.1, C395.1, C400.1, J79.15, R157.2, U118.1, U119.5, U120.4, U120.6, U120.18
5V40: C403.1, C405.1, C410.1, J81.15, R161.2, U121.1, U122.5, U123.4, U123.6, U123.18
5V41: C413.1, C415.1, C420.1, J83.15, R165.2, U124.1, U125.5, U126.4, U126.6, U126.18
5V42: C423.1, C425.1, C430.1, J85.15, R169.2, U127.1, U128.5, U129.4, U129.6, U129.18
5V43: C433.1, C435.1, C440.1, J87.15, R173.2, U130.1, U131.5, U132.4, U132.6, U132.18
5V44: C443.1, C445.1, C450.1, J89.15, R177.2, U133.1, U134.5, U135.4, U135.6, U135.18
5V45: C453.1, C455.1, C460.1, J91.15, R181.2, U136.1, U137.5, U138.4, U138.6, U138.18
5V46: C463.1, C465.1, C470.1, J93.15, R185.2, U139.1, U140.5, U141.4, U141.6, U141.18
5V47: C473.1, C475.1, C480.1, J95.15, R189.2, U142.1, U143.5, U144.4, U144.6, U144.18
5V48: C483.1, C485.1, C490.1, J97.15, R193.2, U145.1, U146.5, U147.4, U147.6, U147.18
5V49: C493.1, C495.1, C500.1, J99.15, R197.2, U148.1, U149.5, U150.4, U150.6, U150.18
5V50: C503.1, C505.1, C510.1, J101.15, R201.2, U151.1, U152.5, U153.4, U153.6, U153.18
5V51: C513.1, C515.1, C520.1, J103.15, R205.2, U154.1, U155.5, U156.4, U156.6, U156.18
5V52: C523.1, C525.1, C530.1, J105.15, R209.2, U157.1, U158.5, U159.4, U159.6, U159.18
5V53: C533.1, C535.1, C540.1, J107.15, R213.2, U160.1, U161.5, U162.4, U162.6, U162.18
5V54: C543.1, C545.1, C550.1, J109.15, R217.2, U163.1, U164.5, U165.4, U165.6, U165.18
5V55: C553.1, C555.1, C560.1, J111.15, R221.2, U166.1, U167.5, U168.4, U168.6, U168.18
5V56: C563.1, C565.1, C570.1, J113.15, R225.2, U169.1, U170.5, U171.4, U171.6, U171.18
5V57: C573.1, C575.1, C580.1, J115.15, R229.2, U172.1, U173.5, U174.4, U174.6, U174.18
5V58: C583.1, C585.1, C590.1, J117.15, R233.2, U175.1, U176.5, U177.4, U177.6, U177.18
5V59: C593.1, C595.1, C600.1, J119.15, R237.2, U178.1, U179.5, U180.4, U180.6, U180.18
5V60: C603.1, C605.1, C610.1, J121.15, R241.2, U181.1, U182.5, U183.4, U183.6, U183.18
5V61: C613.1, C615.1, C620.1, J123.15, R245.2, U184.1, U185.5, U186.4, U186.6, U186.18
5V62: C623.1, C625.1, C630.1, J125.15, R249.2, U187.1, U188.5, U189.4, U189.6, U189.18
5V63: C633.1, C635.1, C640.1, J127.15, R253.2, U190.1, U191.5, U192.4, U192.6, U192.18
A0: J2.7, U3.23
A1: J2.6, U3.24
A2: J2.5, U3.25
A3: J2.4, U3.26
A4: J2.3, U3.27
A5: J2.2, U3.28
A6: J3.7, U6.23
A7: J3.6, U6.24
A8: J3.5, U6.25
A9: J3.4, U6.26
A10: J3.3, U6.27
A11: J3.2, U6.28
A12: J5.7, U9.23
A13: J5.6, U9.24
A14: J5.5, U9.25
A15: J5.4, U9.26
A16: J5.3, U9.27
A17: J5.2, U9.28
A18: J7.7, U12.23
A19: J7.6, U12.24
A20: J7.5, U12.25
A21: J7.4, U12.26
A22: J7.3, U12.27
A23: J7.2, U12.28
A24: J9.7, U15.23
A25: J9.6, U15.24
A26: J9.5, U15.25
A27: J9.4, U15.26
A28: J9.3, U15.27
A29: J9.2, U15.28
A30: J11.7, U18.23
A31: J11.6, U18.24
A32: J11.5, U18.25
A33: J11.4, U18.26
A34: J11.3, U18.27
A35: J11.2, U18.28
A36: J13.7, U21.23
A37: J13.6, U21.24
A38: J13.5, U21.25
A39: J13.4, U21.26
A40: J13.3, U21.27
A41: J13.2, U21.28
A42: J15.7, U24.23
A43: J15.6, U24.24
A44: J15.5, U24.25
A45: J15.4, U24.26
A46: J15.3, U24.27
A47: J15.2, U24.28
A48: J17.7, U27.23
A49: J17.6, U27.24
A50: J17.5, U27.25
A51: J17.4, U27.26
A52: J17.3, U27.27
A53: J17.2, U27.28
A54: J19.7, U30.23
A55: J19.6, U30.24
A56: J19.5, U30.25
A57: J19.4, U30.26
A58: J19.3, U30.27
A59: J19.2, U30.28
A60: J21.7, U33.23
A61: J21.6, U33.24
A62: J21.5, U33.25
A63: J21.4, U33.26
A64: J21.3, U33.27
A65: J21.2, U33.28
A66: J23.7, U36.23
A67: J23.6, U36.24
A68: J23.5, U36.25
A69: J23.4, U36.26
A70: J23.3, U36.27
A71: J23.2, U36.28
A72: J25.7, U39.23
A73: J25.6, U39.24
A74: J25.5, U39.25
A75: J25.4, U39.26
A76: J25.3, U39.27
A77: J25.2, U39.28
A78: J27.7, U42.23
A79: J27.6, U42.24
A80: J27.5, U42.25
A81: J27.4, U42.26
A82: J27.3, U42.27
A83: J27.2, U42.28
A84: J29.7, U45.23
A85: J29.6, U45.24
A86: J29.5, U45.25
A87: J29.4, U45.26
A88: J29.3, U45.27
A89: J29.2, U45.28
A90: J31.7, U48.23
A91: J31.6, U48.24
A92: J31.5, U48.25
A93: J31.4, U48.26
A94: J31.3, U48.27
A95: J31.2, U48.28
A96: J33.7, U51.23
A97: J33.6, U51.24
A98: J33.5, U51.25
A99: J33.4, U51.26
A100: J33.3, U51.27
A101: J33.2, U51.28
A102: J35.7, U54.23
A103: J35.6, U54.24
A104: J35.5, U54.25
A105: J35.4, U54.26
A106: J35.3, U54.27
A107: J35.2, U54.28
A108: J37.7, U57.23
A109: J37.6, U57.24
A110: J37.5, U57.25
A111: J37.4, U57.26
A112: J37.3, U57.27
A113: J37.2, U57.28
A114: J39.7, U60.23
A115: J39.6, U60.24
A116: J39.5, U60.25
A117: J39.4, U60.26
A118: J39.3, U60.27
A119: J39.2, U60.28
A120: J41.7, U63.23
A121: J41.6, U63.24
A122: J41.5, U63.25
A123: J41.4, U63.26
A124: J41.3, U63.27
A125: J41.2, U63.28
A126: J43.7, U66.23
A127: J43.6, U66.24
A128: J43.5, U66.25
A129: J43.4, U66.26
A130: J43.3, U66.27
A131: J43.2, U66.28
A132: J45.7, U69.23
A133: J45.6, U69.24
A134: J45.5, U69.25
A135: J45.4, U69.26
A136: J45.3, U69.27
A137: J45.2, U69.28
A138: J47.7, U72.23
A139: J47.6, U72.24
A140: J47.5, U72.25
A141: J47.4, U72.26
A142: J47.3, U72.27
A143: J47.2, U72.28
A144: J49.7, U75.23
A145: J49.6, U75.24
A146: J49.5, U75.25
A147: J49.4, U75.26
A148: J49.3, U75.27
A149: J49.2, U75.28
A150: J51.7, U78.23
A151: J51.6, U78.24
A152: J51.5, U78.25
A153: J51.4, U78.26
A154: J51.3, U78.27
A155: J51.2, U78.28
A156: J53.7, U81.23
A157: J53.6, U81.24
A158: J53.5, U81.25
A159: J53.4, U81.26
A160: J53.3, U81.27
A161: J53.2, U81.28
A162: J55.7, U84.23
A163: J55.6, U84.24
A164: J55.5, U84.25
A165: J55.4, U84.26
A166: J55.3, U84.27
A167: J55.2, U84.28
A168: J57.7, U87.23
A169: J57.6, U87.24
A170: J57.5, U87.25
A171: J57.4, U87.26
A172: J57.3, U87.27
A173: J57.2, U87.28
A174: J59.7, U90.23
A175: J59.6, U90.24
A176: J59.5, U90.25
A177: J59.4, U90.26
A178: J59.3, U90.27
A179: J59.2, U90.28
A180: J61.7, U93.23
A181: J61.6, U93.24
A182: J61.5, U93.25
A183: J61.4, U93.26
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

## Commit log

2014-03-11 Initial commit of hardware files
    [MicroView-PCB-Assembly_SCALED.skp, SparkFun-MicroView.brd, SparkFun-MicroView.sch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]
2014-03-11 Revamping file names
    [SparkFun-MicroView.brd, SparkFun-MicroView.sch, SparkFun-MicroViewUSB.brd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]
2014-03-11 Adding fids to both boards
    [MicroView.brd, MicroView.sch, MicroViewUSB.brd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]
2014-03-11 Staggering/increasing drill on headers
    Also spacing out resistors, increasing header fp on MicroViewUSB.
    [MicroView.brd, MicroView.sch, MicroViewUSB.brd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]
2014-03-12 Updating r's and c's on USB board to prod. parts
    Also rearranging some silk and traces.
    [MicroViewUSB.brd, MicroViewUSB.sch]
2014-03-12 Moving labels on USB board up a bit
    They're probably still going to be overlapped by the header, but this'll
    help a bit.
    [MicroViewUSB.brd]
2014-03-12 Created proto panel v01
    [MicroView-ProtoPanel-v01.brd]
2014-04-14 Microview v02 -- new resistors and 3.3Vreg change
    * Added pull-down resistor to OLED Reset. Also moved that pin to D7 on
    the Arduino.
    * Added pull-up resistor to D10/SS.
    * Moved 3.3V regulator input to the 5V line (from Vin)
    [MicroView.brd, MicroView.sch]
2014-04-14 Updating version # on schematic (v02)
    [MicroView.sch]
2014-04-14 Moving USB connector position (MVUSB v02)
    Also added silk to indicate polarity of MV.
    [MicroViewUSB.brd, MicroViewUSB.sch]
2014-04-14 Moving silk indicator on MV-USB a bit.
    [MicroViewUSB.brd]
2014-04-14 Tying 3.3V reg enable to an ATmega pin (D4)
    [MicroView.brd, MicroView.sch]
2014-04-17 deleted old proto panel
    [MicroView-ProtoPanel-v01.brd]
2014-04-18 Created panels
    Both Giant and regular for small stencil
    [MicroViewUSB-GiantPanel-v02.brd, MicroViewUSB-Panel-v02.brd]
2014-04-22 Series resistors on MOSI and SCK (v03)
    Limits current into OLED I/O lines. This in conjunction with some code
    changes will help to protect the display from overvoltage.
    This required removing pull-down resistor to RESET and pull-up to SS.
    BUT! You can still program the display, using an ICSP, with the series
    resistors on MOSI and SCK.
    [MicroView.brd, MicroView.sch]
2014-04-28 Added windowed upper housing
    Created windowed upper housing for printing in 3d printers with opaque
    material
    [GKM-002_R05_CHIP_WINDOWED_UPPER_HOUSING.stl]
2014-05-13 Moving some silk around. Production boards (v10).
    [MicroView.brd, MicroView.sch]
2014-05-13 created panel v10
    [MicroView-Panel-v10.brd]
2014-05-13 created giant panel
    [MicroView-GiantPanel-v10.brd]
2015-01-15 Moving STL files to Enclosure directory
    [GKM-001_R05_ASSY_CHIP - GKM-002_R05_CHIP_UPPER_HOUSING-1.STL, GKM-001_R05_ASSY_CHIP - GKM-003_R05_CHIP_LOWER_HOUSING-1.STL, GKM-001_R05_ASSY_CHIP - GKM-004_R02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]
2015-01-15 Updating README, moving files around to clarify repo structure
    [MicroViewUSB-GiantPanel-v02.brd, MicroViewUSB-Panel-v02.brd, MicroViewUSB.brd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]
2015-04-24 Squashed 'Libraries/Arduino/' content from commit 646247d
    git-subtree-dir: Libraries/Arduino
    git-subtree-split: 646247d149665aa62a394e1d9a87c6b272d31f88
2015-04-28 Squashed 'Libraries/Arduino/' changes from 646247d..f3741f5
    git-subtree-split: f3741f5f72b6e2bb11d250358e2f893ce52b99f9
    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
2015-04-28 Fixing production directory name
    [MicroView-GiantPanel-v10.brd, MicroView-Panel-v10.brd]
2025-06-27 Update Circuit8.ino
    Updating link

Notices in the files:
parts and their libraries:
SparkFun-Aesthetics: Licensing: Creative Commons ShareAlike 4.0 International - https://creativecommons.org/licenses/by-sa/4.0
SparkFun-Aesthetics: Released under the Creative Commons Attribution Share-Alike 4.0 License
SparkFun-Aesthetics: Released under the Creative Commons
